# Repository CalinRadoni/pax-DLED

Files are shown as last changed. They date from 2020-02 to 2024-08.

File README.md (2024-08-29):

# ESP32 controller for digital LEDs

Efficiency, hardware control for digital LEDs and Wi-Fi communications - these are just some of the caracteristics of this controller.

It is designed to control digital LEDS like:

- WS2812, WS2812B, ... (*aka* NeoPixel) and derivatives like SK6812
- APA102 (*aka* DotStar) and derivatives like SK9822

**Status:** *this is work in progress !*

## Features

- using the ESP32's RMT peripheral, the controller is able to drive two strips of digital LEDs like: WS2812, WS2812B, WS2812C, WS2812S, WS2813, WS2815, WS2812D, etc.
- using the ESP32's HSPI peripheral, the controller is able to drive a strip of digital LEDs like APA102
- two *real* logic level shifter circuits
- the power supply for LEDs is controlled using a Power MOSFET
- I2C and two general-purpose extension headers
- high efficiency synchronous buck converter
- supply voltage supervisor

## Software

My [esp32_digitalLEDs](https://github.com/CalinRadoni/esp32_digitalLEDs) repository contains code to use the ESP32's RMT peripheral to drive digital LEDs.

The code dedicated to this board is not yet built.

## Development Environment

Operating system is [Debian](https://www.debian.org/)

Tools:

- [KiCad EDA](https://www.kicad.org/)
- [Visual Studio Code](https://code.visualstudio.com/)
- [Espressif IoT Development Framework](https://github.com/espressif/esp-idf)
- [Git](https://git-scm.com/)
- [GIMP](https://www.gimp.org/)
- [Inkscape](https://inkscape.org/en/)

## Versions

### Version 1

- *Fab* files are moved to the Fab-v1 directory
- The PCBs from SeeedStudio arrived
- The components are sourced
- I have built three boards
- I have developed a proof-of-concept software

### Version 0.x

Hardware revision 10 is presented in the following rendered picture:

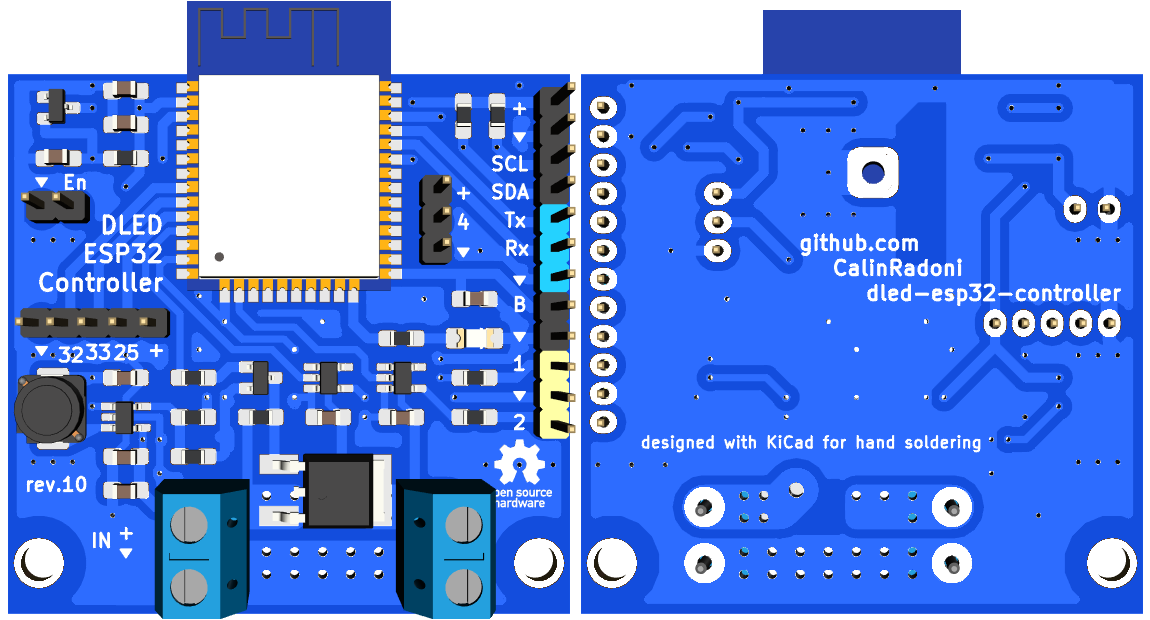
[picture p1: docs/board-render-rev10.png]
board-render


Hardware revision 9 is presented in the following rendered picture:

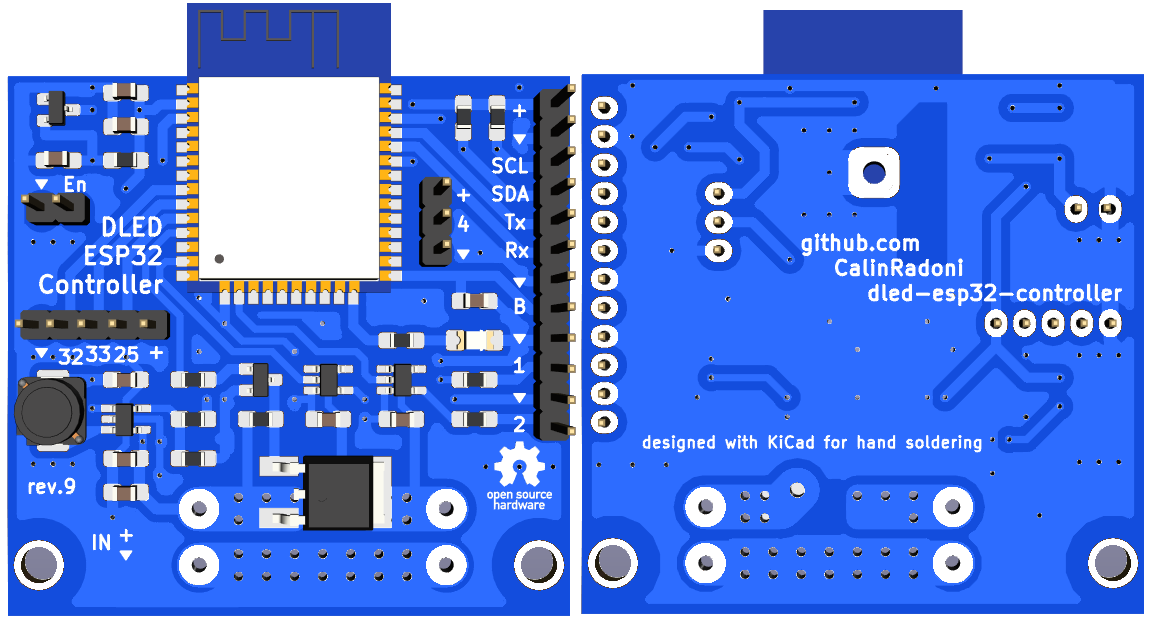
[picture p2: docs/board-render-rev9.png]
board-render


Hardware revision 8 is presented in the following rendered picture:

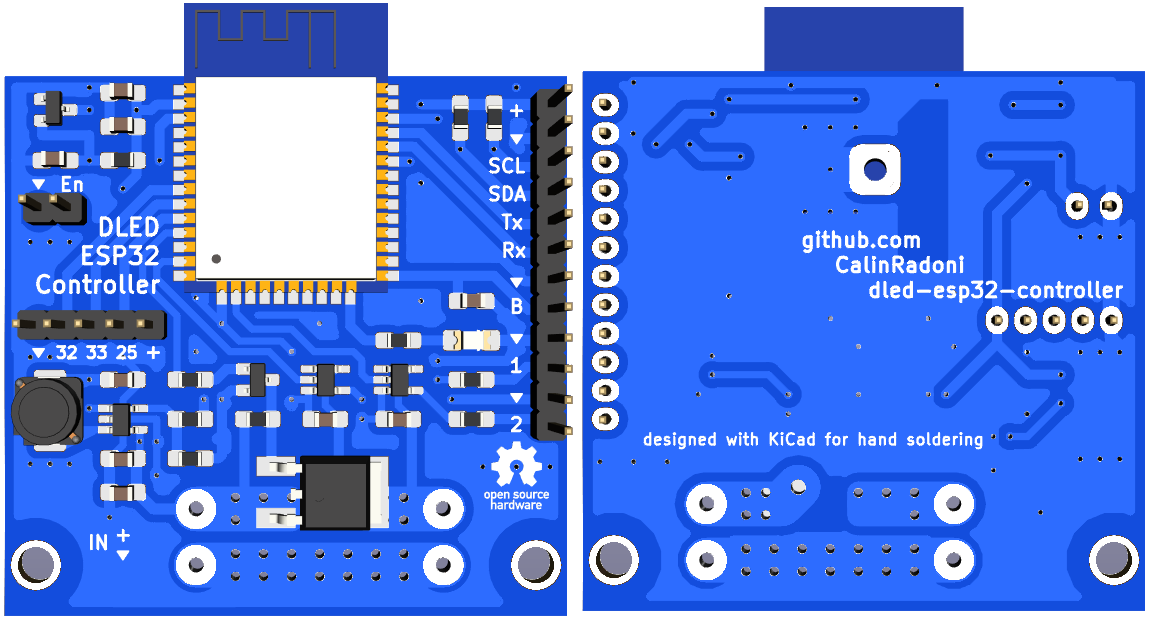
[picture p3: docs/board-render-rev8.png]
board-render


## License

The software and documentation are released under the [GNU GPLv3](http://www.gnu.org/licenses/gpl-3.0.html) License. See the __LICENSE-GPLv3.txt__ file.

The hardware schematics are licensed under a [Creative Commons Attribution-ShareAlike 4.0 International License](http://creativecommons.org/licenses/by-sa/4.0/).
See the __LICENSE-CC-BY-SA-4.0.txt__ file.

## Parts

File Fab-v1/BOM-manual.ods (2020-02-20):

Reference | Value | Footprint | characteristics | manufacturer | package | part-number | Qty | 3
C1, C2, C5, C6, C9 | 100nF | CalinGeneric:C0805HS | 100 nF / 50V / X7R | Samsung | 0805 | CL21B104KBCNNNC | 5 | 15
C3 | 10uF | CalinGeneric:C0805HS | 10 µF / 6,3 V | Samsung | 0805 | CL21B106KQQNNNE | 1 | 3
C7 | 10uF/10V/1mOhm | CalinGeneric:C0805HS | 10 µF / 10 V / X5R / ESR: 1 mΩ | Taiyo Yuden | 0805 | EMK212BJ106KG-T | 1 | 3
C8 | 22uF/6.3V/1mOhm | CalinGeneric:C0805HS | 22 µF / 6.3 V / X5R / ESR: 1 mΩ | Taiyo Yuden | 0805 | JMK212BJ226MG-T | 1 | 3
D1 | LED | CalinGeneric:LED1206 | * | Optoflash | 1206 | OF-SMD3216B | 1 | 3
J1 | CS_4 | CalinConnectors:Pin_Header_Straight_1x04 |  |  |  | ph4 | 1 | 3
J2 | CS_3 | CalinConnectors:Pin_Header_Straight_1x03_Cyan |  |  |  | ph3_cyan | 1 | 3
J3, J4 | CS_2 | CalinConnectors:Pin_Header_Straight_1x02 |  |  |  | ph_2 | 2 | 6
J5 | CS_3 | CalinConnectors:Pin_Header_Straight_1x03_Yellow |  |  |  | ph3_yellow | 1 | 3
J8, J9 | CS_Pwr | CalinConnectors:DG301-5-2 | 5mm pitch, 2 pins, 10A |  |  | tb_5mm_2pins | 2 | 6
L1 | 2.2uH | CalinGeneric:ASPI-0530HI | 2.2 uH DCR: 35 mΩ | Abracon Corporation | * | ASPI-0530HI-2R2M-T2 | 1 | 3
Q1 | STD46P4LLF6 | CalinOLD:TO-252 | * | STMicroelectronics | DPAK (TO-252) | STD46P4LLF6 | 1 | 3
Q2 | IRLML2502 | CalinGeneric:SOT-23-GSD-HS | * | International Rectifier | SOT23-3 | IRLML2502GPbF | 1 | 3
R1, R8 | 10k | CalinGeneric:R0805HS | * | Vishay | 0805 | CRCW080510K0FKEA | 2 | 6
R3, R4 | 2k2 | CalinGeneric:R0805HS | 2K | Panasonic | 0805 | ERJ-6ENF2201V | 2 | 6
R2,R5,R9,R10 | 330 | CalinGeneric:R0805HS | * | Vishay | 0805 | CRCW0805330RFKTABC | 4 | 12
R6 | 442k 1% | CalinGeneric:R0805HS | 442Kohms 1% | Panasonic | 0805 | ERJ-6ENF4423V | 1 | 3
R7 | 100k 1% | CalinGeneric:R0805HS | 100Kohms 1% | Panasonic | 0805 | ERJ-6ENF1003V | 1 | 3
U1 | ESP-WROOM-32 | CalinGeneric:ESP-WROOM-32-HandSolder | * | Espressif | * | ESP32-WROOM-32 | 1 | 3
U2 | BD48K28...30 | CalinGeneric:SOT-23-HS |  | ROHM Semiconductor | SSOP3 (SOT23-3) | BD48K30G-TL | 1 | 3
U3 | TLV62569DBV | CalinGeneric:SOT-23-5-HS |  | Texas Instruments | SOT23-5 | TLV62569DBV | 1 | 3
U4, U5 | SN74LV1T34 | CalinGeneric:SOT-23-5-HS |  | Texas Instruments | SOT23-5 | SN74LV1T34DBVR | 2 | 6

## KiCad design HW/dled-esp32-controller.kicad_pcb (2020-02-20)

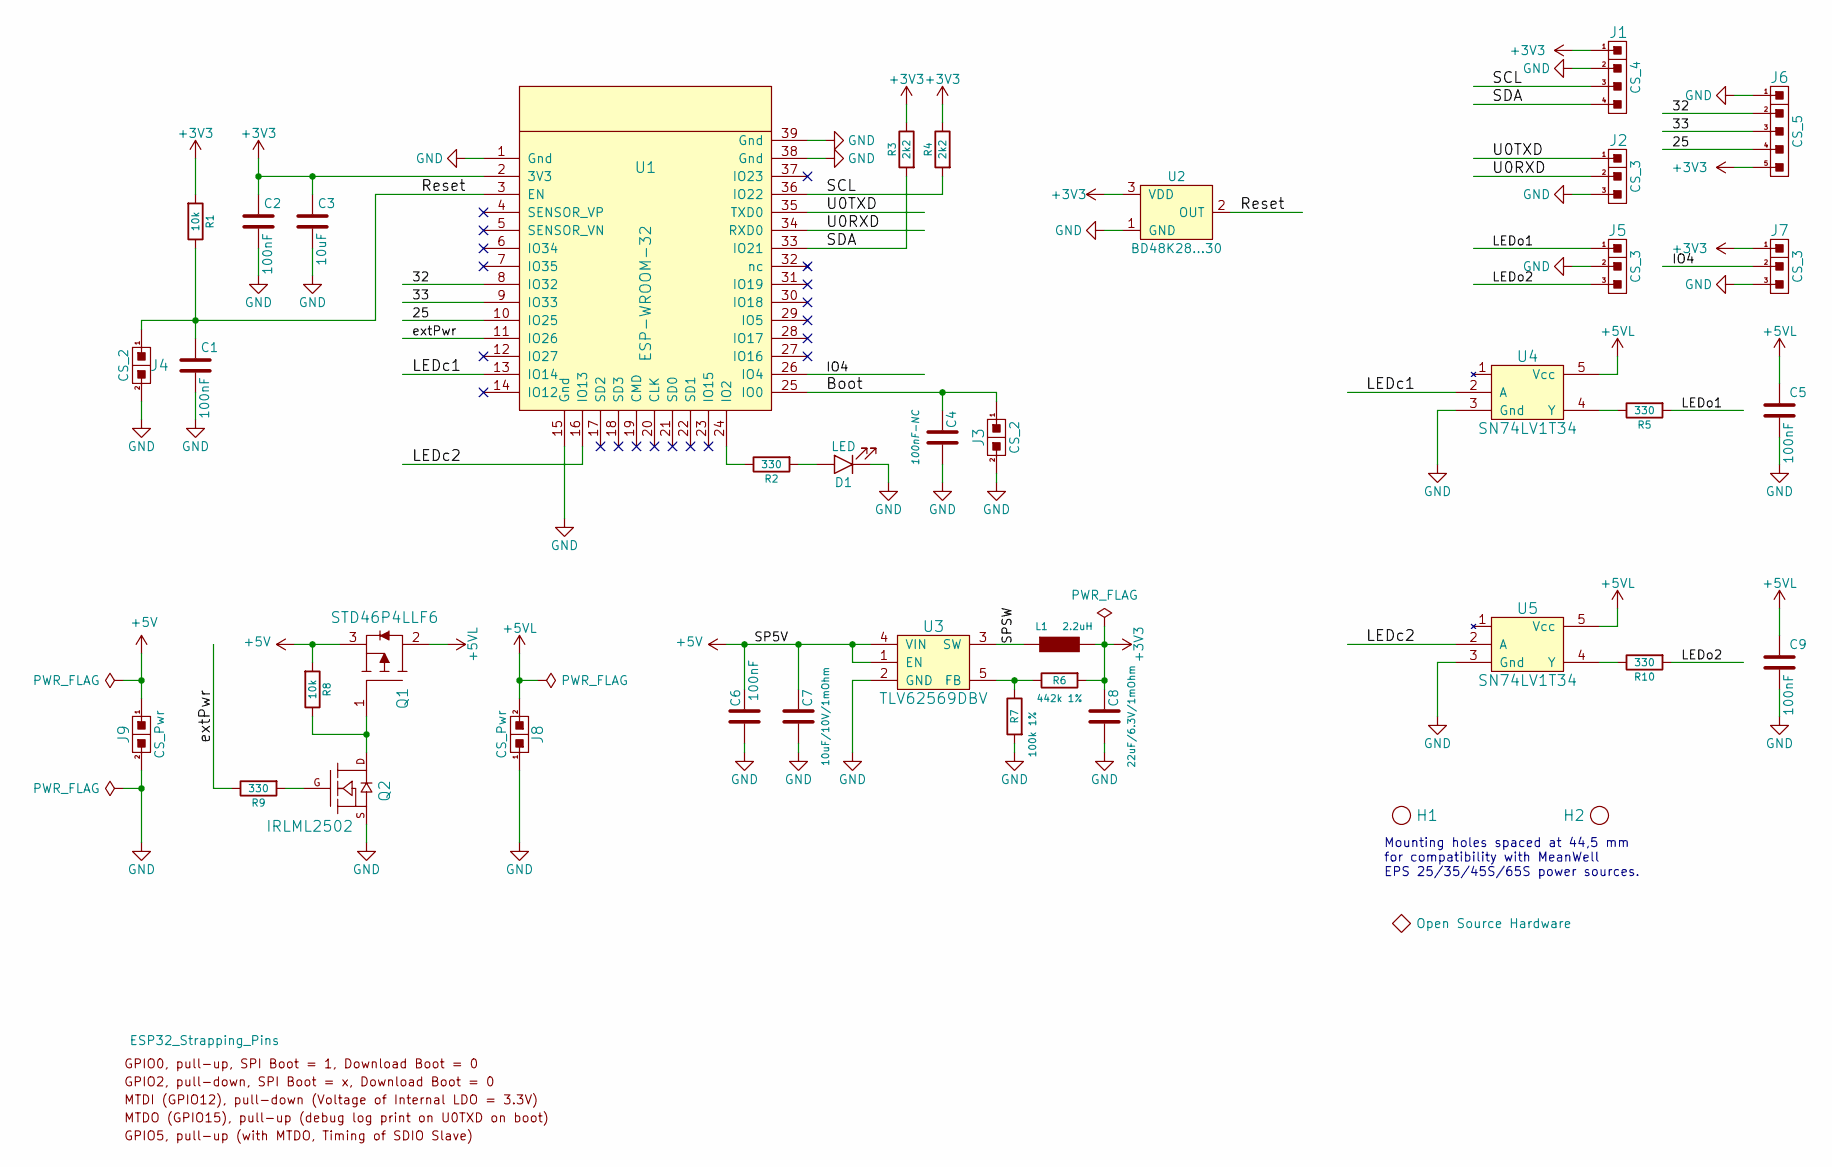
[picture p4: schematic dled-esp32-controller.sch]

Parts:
C1, C2, C5, C6, C9: 100nF; C0805HS; part-number CL21B104KBCNNNC
C3: 10uF; C0805HS; part-number CL21B106KQQNNNE
C4: 100nF-NC; C0805HS; part-number DNP
C7: 10uF/10V/1mOhm; C0805HS; part-number EMK212BJ106KG-T
C8: 22uF/6.3V/1mOhm; C0805HS; part-number JMK212BJ226MG-T
D1: LED; LED1206; part-number OF-SMD3216B
H1, H2: Hole; HoleNPT-M3; part-number DNP
J1: CS_4; Pin_Header_Straight_1x04
J2: CS_3; Pin_Header_Straight_1x03_Cyan
J3, J4: CS_2; Pin_Header_Straight_1x02
J5: CS_3; Pin_Header_Straight_1x03_Yellow
J6: CS_5; Pin_Header_Straight_1x05; part-number DNP
J7: CS_3; Pin_Header_Straight_1x03; part-number DNP
J8, J9: CS_Pwr; DG301-5-2
L1: 2.2uH; ASPI-0530HI; part-number ASPI-0530HI-2R2M-T2
Q1: STD46P4LLF6; TO-252; part-number STD46P4LLF6
Q2: IRLML2502; SOT-23-GSD-HS; part-number IRLML2502GPbF
R1, R8: 10k; R0805HS; part-number CRCW080510K0FKEA
R2, R5, R9, R10: 330; R0805HS; part-number CRCW0805330RFKTABC
R3, R4: 2k2; R0805HS; part-number ERJ-6ENF2201V
R6: 442k 1%; R0805HS; part-number ERJ-6ENF4423V
R7: 100k 1%; R0805HS; part-number ERJ-6ENF1003V
SYM1: Open Source Hardware; OSHW-Logo_5.7x6mm_SilkScreen; part-number DNP
U1: ESP-WROOM-32; ESP-WROOM-32-HandSolder; part-number ESP32-WROOM-32
U2: BD48K28...30; SOT-23-HS; part-number BD48K30G-TL
U3: TLV62569DBV; SOT-23-5-HS; part-number TLV62569DBV
U4, U5: SN74LV1T34; SOT-23-5-HS; part-number SN74LV1T34DBVR

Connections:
+3V3: C2.1, C3.1, C8.1, J1.1, J6.5, J7.1, L1.2, R1.1, R3.2, R4.2, R6.1, U1.2 (3V3), U2.3 (VDD)
+5V: C6.1, C7.1, J9.1, Q1.3, R8.1, U3.1 (EN), U3.4 (VIN)
+5VL: C5.1, C9.1, J8.2, Q1.2, U4.5 (Vcc), U5.5 (Vcc)
/25: J6.4, U1.10 (IO25)
/32: J6.2, U1.8 (IO32)
/33: J6.3, U1.9 (IO33)
/Boot: C4.1, J3.1, U1.25 (IO0)
/IO4: J7.2, U1.26 (IO4)
/LEDc1: U1.13 (IO14), U4.2 (A)
/LEDc2: U1.16 (IO13), U5.2 (A)
/LEDo1: J5.1, R5.1
/LEDo2: J5.3, R10.1
/Reset: C1.1, J4.1, R1.2, U1.3 (EN), U2.2 (OUT)
/SCL: J1.3, R4.1, U1.36 (IO22)
/SDA: J1.4, R3.1, U1.33 (IO21)
/SPSW: L1.1, U3.3 (SW)
/U0RXD: J2.2, U1.34 (RXD0)
/U0TXD: J2.1, U1.35 (TXD0)
/extPwr: R9.2, U1.11 (IO26)
GND: C1.2, C2.2, C3.2, C4.2, C5.2, C6.2, C7.2, C8.2, C9.2, D1.K, J1.2, J2.3, J3.2, J4.2, J5.2, J6.1, J7.3, J8.1, J9.2, Q2.S, R7.1, U1.1 (Gnd), U1.15 (Gnd), U1.38 (Gnd), U1.39 (Gnd), U2.1 (GND), U3.2 (GND), U4.3 (Gnd), U5.3 (Gnd)
unnamed: D1.A, R2.1
unnamed: Q1.1, Q2.D, R8.2
unnamed: Q2.G, R9.1
unnamed: R2.2, U1.24 (IO2)
unnamed: R5.2, U4.4 (Y)
unnamed: R6.2, R7.2, U3.5 (FB)
unnamed: R10.2, U5.4 (Y)

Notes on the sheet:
Mounting holes spaced at 44,5 mm for compatibility with MeanWell EPS 25/35/45S/65S power sources.

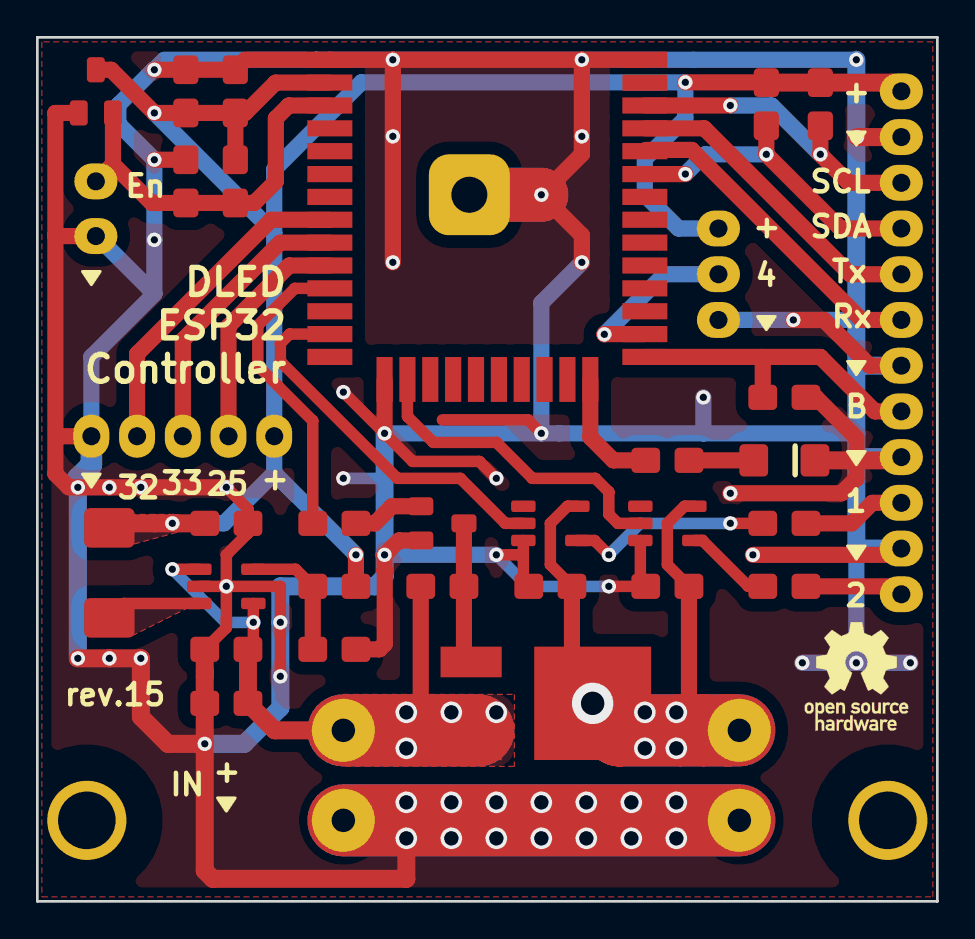
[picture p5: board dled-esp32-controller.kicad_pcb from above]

Board: 2 copper layers, 50.0 x 48.0 mm, 40 parts (0 on the bottom side), 27 nets.

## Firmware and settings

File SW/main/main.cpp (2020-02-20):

/**
This file is part of pax-devices (https://github.com/CalinRadoni/pax-devices)
Copyright (C) 2019+ by Calin Radoni

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
You should have received a copy of the GNU General Public License
along with this program.  If not, see <http://www.gnu.org/licenses/>.
*/

#include "freertos/FreeRTOS.h"
#include "freertos/task.h"
#include "esp_err.h"
#include "esp_log.h"
#include "esp_system.h"

#include <string.h>

#include "driver/ledc.h"

#include "BoardDev33.h"

#include "DStrip.h"
#include "DLEDController.h"
#include "ESP32Timers.h"

#include "sdkconfig.h"

const char* TAG = "Init";

static const uint16_t cfgLEDcount = (uint16_t)(CONFIG_NUMBER_OF_LEDS & 0xFFFF);
static const uint8_t  cfgMaxCCV = (uint8_t)(CONFIG_MAX_LED_COLOR_VALUE & 0xFF);

static const uint32_t dTimerPeriod = 5; // ms
static const uint32_t dTimerPPS = 1000 / dTimerPeriod;

// TODO: Make a class to control the onboard LED based on the driver/ledc API

BoardDev33 board;
DStrip strip;
DLEDController LEDcontroller;
ESP32RMTChannel rmt0;
uint32_t seconds = 0;

extern "C" {

    static void TimerTask(void *taskParameter) {
        uint32_t animationTick = 0;
        uint32_t secondTick = 0;
        ESP32TimerEvent timerEvent;
        uint16_t step = 64;

        strip.Create(3, cfgLEDcount, cfgMaxCCV);
        rmt0.Initialize((rmt_channel_t)0, (gpio_num_t)14, cfgLEDcount * 24);
        rmt0.ConfigureForWS2812x();
        LEDcontroller.SetLEDType(LEDType::WS2812);

        board.PowerOn();

        LEDcontroller.SetLEDs(strip.description.data, strip.description.dataLen, &rmt0);

        board.debouncer.SetUpdateTime(dTimerPeriod);
        board.debouncer.SetKeyRepeat(500, 50);

        for(;;) {
            if (xQueueReceive(timers.timerQueue, &timerEvent, portMAX_DELAY) == pdPASS) {
                if (timerEvent.group == timer_group_t::TIMER_GROUP_0) {
                    if (timerEvent.index == timer_idx_t::TIMER_0) {
                        // read and debounce onboard button
                        board.debouncer.Update(board.OnboardButtonPressed());

                        animationTick++;
                        if (animationTick >= 10) {
                            animationTick -= 10;
                            strip.MovePixel(step);
                            step++;

                            // Display a frame
                            LEDcontroller.SetLEDs(strip.description.data, strip.description.dataLen, &rmt0);
                        }

                        secondTick++;
                        if (secondTick >= dTimerPPS) {
                            secondTick -= dTimerPPS;
                            seconds++;
                        }
                    }
                }
            }
        }

        // the next lines are here only for "completion"
        timers.DestroyTimer(timer_group_t::TIMER_GROUP_0, timer_idx_t::TIMER_0);
        timers.Destroy();
        vTaskDelete(NULL);
    }

    void app_main()
    {

        // TODO Add git-based app version (https://docs.espressif.com/projects/esp-idf/en/latest/api-reference/system/system.html#app-version)

        esp_err_t err = board.Initialize();
        if (err != ESP_OK) {
            ESP_LOGE(TAG, "Initialization failed !");
            board.DoNothingForever();
        }

        if (!board.CheckConfiguration()) {
            // After this call the board will restart, no matter what
            board.StartConfigurationAP();
        }

        err = board.InitializeWiFi();
        if (err != ESP_OK) {
            ESP_LOGE(TAG, "0x%x Failed to initialize WiFi !", err);
            board.GoodBye();
        }

        err = board.Connect();
        if (err != ESP_OK) {
            ESP_LOGE(TAG, "0x%x Failed to connect !", err);
            board.GoodBye();
        }

        if (!timers.Create()) {
            ESP_LOGE(TAG, "Failed to create the timers object !");
            board.DoNothingForever();
        }

        if (!timers.CreateTimer(timer_group_t::TIMER_GROUP_0, timer_idx_t::TIMER_0, dTimerPeriod, true, false)) {
            ESP_LOGE(TAG, "Failed to create the timer G0T0 !");
            board.DoNothingForever();
        }

        TaskHandle_t xHandleTimerTask = NULL;
        xTaskCreate(TimerTask, "Timer handling task", 2048, NULL, uxTaskPriorityGet(NULL) + 5, &xHandleTimerTask);
        if (xHandleTimerTask != NULL) {
            ESP_LOGI(TAG, "Timer task created.");
        }
        else {
            ESP_LOGE(TAG, "Failed to create the timer task !");
            board.DoNothingForever();
        }
    }
}

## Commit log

2020-02-20 Reinitialization after splitting from pax-devices repository
    [BOM-manual.ods, Configuration.h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]
2024-08-29 Update KiCad link

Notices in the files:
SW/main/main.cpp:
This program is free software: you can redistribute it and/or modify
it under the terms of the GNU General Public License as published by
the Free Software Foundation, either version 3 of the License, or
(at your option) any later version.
